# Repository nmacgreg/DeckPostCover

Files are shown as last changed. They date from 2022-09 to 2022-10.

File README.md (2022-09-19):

# Deck Post Skirt or Footing Trim

* This is a 3D model designed to be printed with an FDM 3D printer
* This "deck post skirt" is a two-piece skirt that fits around the bottom of the post, to hide the base of the post and the bolts holding the foot of the posts to the deck
* These come in two sizes.  The external measurements are the same for both.
    * The first has an opening for a post measuring 52.22mm by 52.22mm
    * The second is unknown at this moment!
* Some words to help with SEO: 
    * Deck post flare
    * Deck post base cover
    * Post base trim
    * Post base cover
    * Railing post base
    * Post skirt dressing

## Status: 2022 Sept. 18, v0.0.2 -  relieved edges

* Improved in several ways: 
    * Thicker walls
    * Rounded edges
    * Better orientation for slicing
* Initial printing says it's not compatible with v0.0.1

## Status: 2022 Sept. 10, v0.0.1 - first version

* This is a work in progress.  
* I printed a pair of these and tried them on the target post.  They fit really nicely.  Quite chuffed at how well they fit, actually, and on first attempt.

## Links

* [Amazon search for these](https://www.amazon.com/Deck-Post-Covers/s?k=Deck+Post+Covers)
* [Amazon search for deck post skirt](https://www.amazon.com/deck-post-skirt/s?k=deck+post+skirt)
* [The Deck Store carries these](https://www.thedeckstore.com/deck-post-caps-and-accessories/posts-post-accessories/deck-rail-post-skirts.html)
* [DecksDirect.com carries these](https://www.decksdirect.com/deck-railing-accessories/deck-fence-post-caps/post-skirts)

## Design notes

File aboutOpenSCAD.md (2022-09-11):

# Things I learned about OpenSCAD on this project

* module() is really powerful!
    * This allows you to define the size, shape, and position of a *component* for your design, in a modular fashion, as a bunch of reusable components to be assembled
    * Then, in the main body of your program, you can use union() and difference() to assemble the pieces together, while using translate()/rotate()/resize() to position them together
    * This means you can use simple text revision-control tools like git, and get great fidelity from looking at changes over time
    * eg, when you make a change to a module, it doesn't affect the rest of the assembly.
* A .scad file is just text, so you can use your favourite text editor to clean it up, if you like

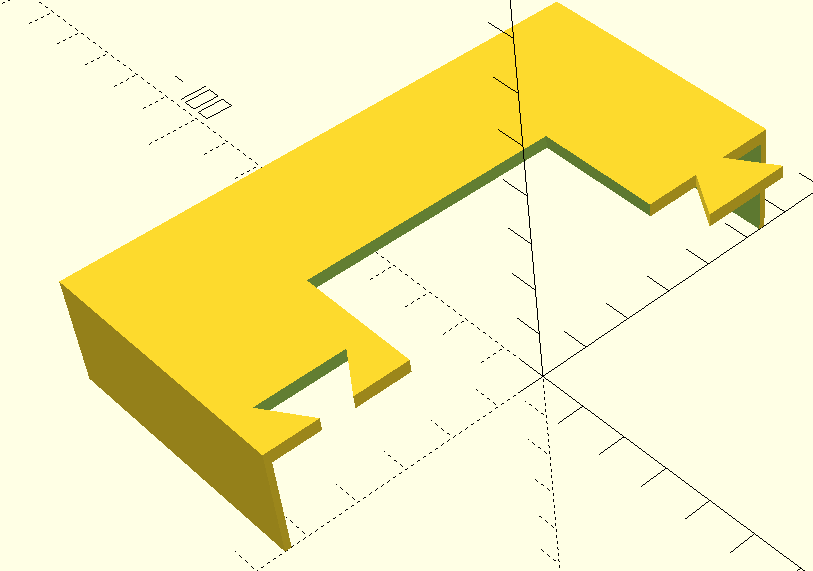
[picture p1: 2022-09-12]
image.png

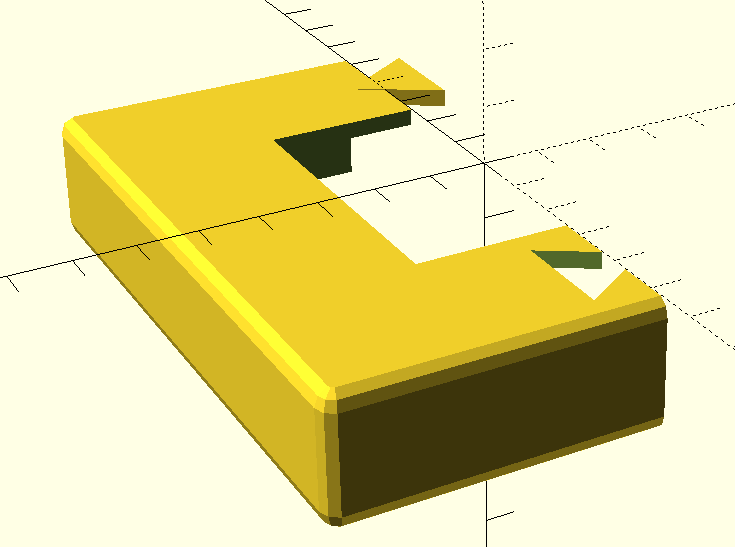
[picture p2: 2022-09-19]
image_v0.0.2.png

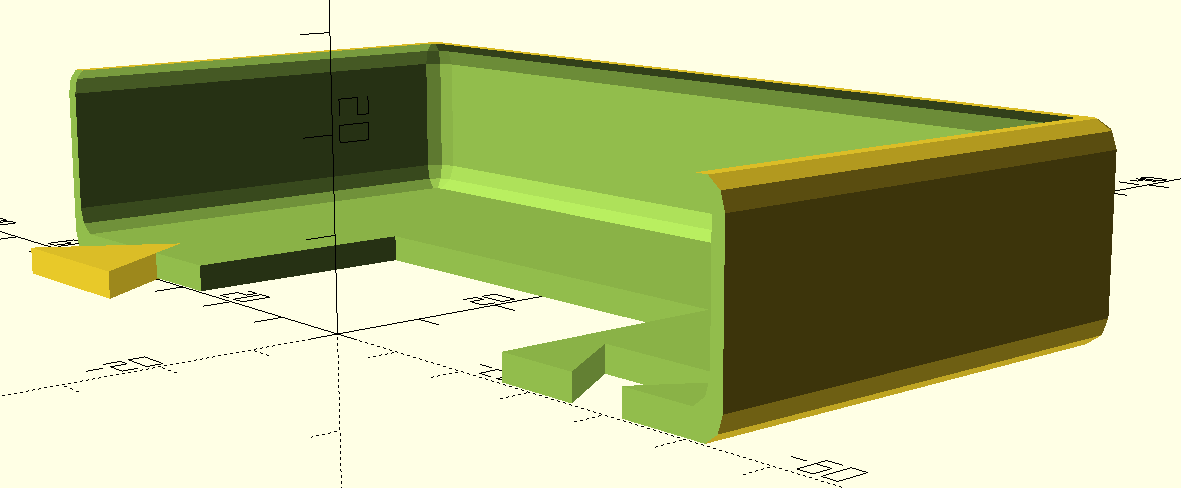
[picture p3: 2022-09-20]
image_v0.0.4.png

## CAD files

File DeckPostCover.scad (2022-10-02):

// This is a complete rewrite.  This time, going for rounded edges!
// This may not be right!  Does the minkowki make it bigger by 2*minkValue(), or 1x?
// My measurements are in mm
minkValue=3;  // Diameter of sphere that will be used for minkowski() rounded edges
Outer=109;  // intended outside dimension
SmallOuter=Outer-(minkValue*2);  // slightly smaller dimensions, where minkowski() will be applied
Height=22.4;
SmallHeight = Height-(minkValue*2);  // The height we'll draw the outer shell, minus effect of minkowski()
CenterSquare=52.22;
CenterSquareHeight=Height;
WallThickness=3.0;
InternalVoid=Outer-WallThickness;
InternalVoidHeight=Height-WallThickness;

module outerShell(){
    translate([0,0,minkValue]) // raise it back to the origin plane, by 1 mink
    difference() {  // subtract the left-hand-side of this rectangle
        minkowski() {  // the minkowski() increases overall dimensions by 2*minkValue
            linear_extrude(height=SmallHeight) 
            square([SmallOuter,SmallOuter], center=true);
            sphere(minkValue);
        };
        translate([Outer/2,0,-minkValue]) 
        linear_extrude(height=Height) 
        square([Outer,Outer+minkValue], center=true); // A slightly larger square
    }
}
module centerPost() {
                // Post, centered
                linear_extrude(height=CenterSquareHeight)
                square(CenterSquare, center=true);
}
module innerHollow() {
    // The inside is hollow
        translate([0,0,(minkValue)]) // raise it back to the origin plane, after mink()
    minkowski() {
        linear_extrude(height=(InternalVoidHeight-(minkValue*2)+0.15)) //bug here!
        square((InternalVoid-(minkValue*2)), center=true);
        sphere(minkValue);
    }
}
// This is just a triangular prism
// I'm going by feel, on this one!
// It would fit in a rectangle with these dimensions:
dogEarX=14; // These values should be calculated from Outer (?)
dogEarY=18;
dogEarYPos=((CenterSquare/2 + ((Outer)/2-CenterSquare/2)/2)-WallThickness/2); // Center of arm
module dogEar() {
    linear_extrude(height=WallThickness) 
    polygon([[0,0], [dogEarX,-(dogEarY/2)], [dogEarX,(dogEarY/2)]]); // It's a triangle
}
clearance=0.1; // a "fudge-factor" for 3D printing, letting parts fit
dogEarStrength=5; // how deep to bury the dogEars
 rotate([0,180,0]) translate([0,0,-(Height)])
    difference() {
        union() {
            difference() {
                difference() {
                    outerShell();
                    centerPost();
                }
                innerHollow();
            }      
            translate([-dogEarStrength, dogEarYPos, (Height-WallThickness-0.2)])
            dogEar(); // add the dogEar, in the right place
        }
        // subtract the dogEar, in the right place, bigger by "clearance"!
        resize([(dogEarX+clearance),(dogEarY+clearance)])
        translate([dogEarStrength, -dogEarYPos, (Height-WallThickness)])
        rotate([0,0,180])    
        dogEar();  
    }

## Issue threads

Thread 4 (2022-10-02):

First layer reveals trouble

nmacgreg, 2022-10-02:
The first layer prints only the dogear, lower than everything else. The second layer has everything else at 0.4mm, so bed adhesion isn't great since it's printed too high, and the surface quality is poor.  I printed 5 copies before I noticed it, and each one had a brown, burned thread of filament somewhere in the surface, too, probably from trying to print it not connected to the bed.

nmacgreg, 2022-10-02:
I raised the dogear by 0.2mm, as a quick workaround. I suspect the root mathematical problem comes from a rounding error from division.  Also, I forgot to use proper etiquette & committed directly to the main branch.

nmacgreg, 2022-10-02:
Leaving this open, as a reminder to fix the 0.2 "fudge factor" on line #64

nmacgreg, 2022-10-13:
Speculative: The dogear() is obviously a polygon, a triangle, on the X-Y plane, then linearly-extruded.

```
module dogEar() {
    linear_extrude(height=WallThickness)
    polygon([[0,0], [dogEarX,-(dogEarY/2)], [dogEarX,(dogEarY/2)]]); // It's a triangle
}
```

So, the "fix" in v1.0.0 of dropping it by 0.2mm below the plane points to the root cause of the problem:  _the body of the model isn't sitting on the X-Y plane!_
And, why would that be?
I think it's line 16, in the outerShell() module: `    translate([0,0,minkValue]) // raise it back to the origin plane, by 1 mink`

... which means the minkowski() is inaccurate, somehow!

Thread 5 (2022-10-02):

Burn spots?

nmacgreg, 2022-10-02:
Each print (in the final white filament) has a brown mark where some of the filament was burnt!  It's in different places, but usually around the edge or the dog-ear.  That's weird.  It continues to happen even in v1.0.0, after raising the dog-ear into the correct plane. I don't know if this is something resulting from the model, or something to do with slicing.  I know that I adjusted the filament bed temperature to 85 seeking to remedy the bed adhesion problem that was a result of the non-planar problem in v0.0.4, and part of the solution might be adjusting bed/nozzle temps.

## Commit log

2022-09-10 Basic dimensions locked
    [DeckPostCover.scad]
2022-09-10 Added the dog-ear, perhaps too big, but won a victory
    [DeckPostCover.scad]
2022-09-10 Converted to use a 'module' for the dogEar triangle
    [DeckPostCover.scad]
2022-09-11 Modularized the first 3 units
    [DeckPostCover.scad]
2022-09-11 Multiple improvements, probably as far as we can go with this model
    [DeckPostCover.scad]
2022-09-11 Added comments to the model
    [DeckPostCover.scad]
2022-09-11 Multiple changes, towards parameterization, and making future changes easier
    [DeckPostCover.scad]
2022-09-11 Simplified the Y position of the dogEar, into an expression
    [DeckPostCover.scad]
2022-09-11 Cleaned up only comments
    [DeckPostCover.scad]
2022-09-11 Changed the name of centerHole to centerPost
    [DeckPostCover.scad]
2022-09-11 Increased the strenght of the dogEar
    [DeckPostCover.scad]
2022-09-18 Added Alternat.scad, experimenting with minkowski() for smoothing corners
    [Alternate.scad]
2022-09-18 Multiple improvements in this new version
    * I flipped it upside down, so the correct face is down when you pull an
    STL into slicing software
    * I moved the model in 3D space so it sits on the origin plane
    * I adjusted the wall thickness to make it a little chunkier
    * I rebuilt the outerShell, now starting with a "full size" extruded
    rectangle to which minkowski() is applied, then sliced away half of
    it, so the mating edges are not beveled.
    [Alternate.scad]
2022-09-19 Copied Alternate to DeckPostCover
    [Alternate.scad, DeckPostCover.scad]
2022-09-20 Many changes; added some comments, but mostly around returning variables 'Outer' and 'Height' to their original meaning, giving the real outer dimensions of the part, making it easier to reason about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
    [DeckPostCover.scad]
2022-09-20 Updated the model with curved internal corners
    [DeckPostCover.scad]
2022-10-02 Resolving issue No. 4, I lowered the 'dogear' by 0.2mm, so it's in the same plane as the rest of the lower surface
    [DeckPostCover.scad]
